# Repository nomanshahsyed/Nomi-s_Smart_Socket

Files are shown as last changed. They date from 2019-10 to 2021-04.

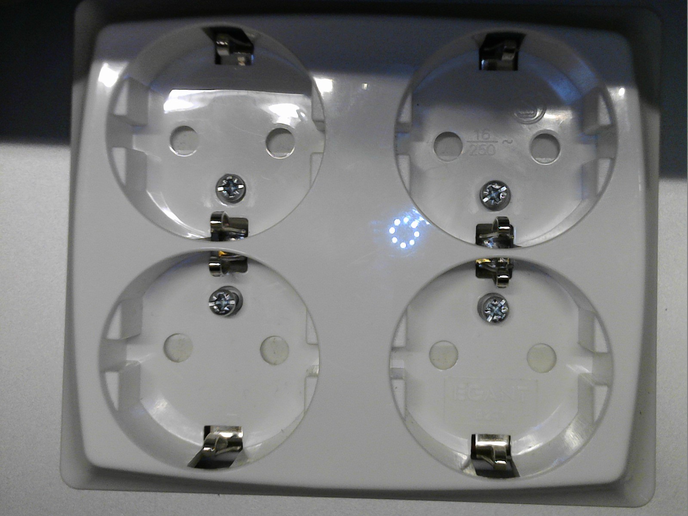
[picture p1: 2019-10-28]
Pictures/WIN_20191028_12_22_07_Pro.jpg

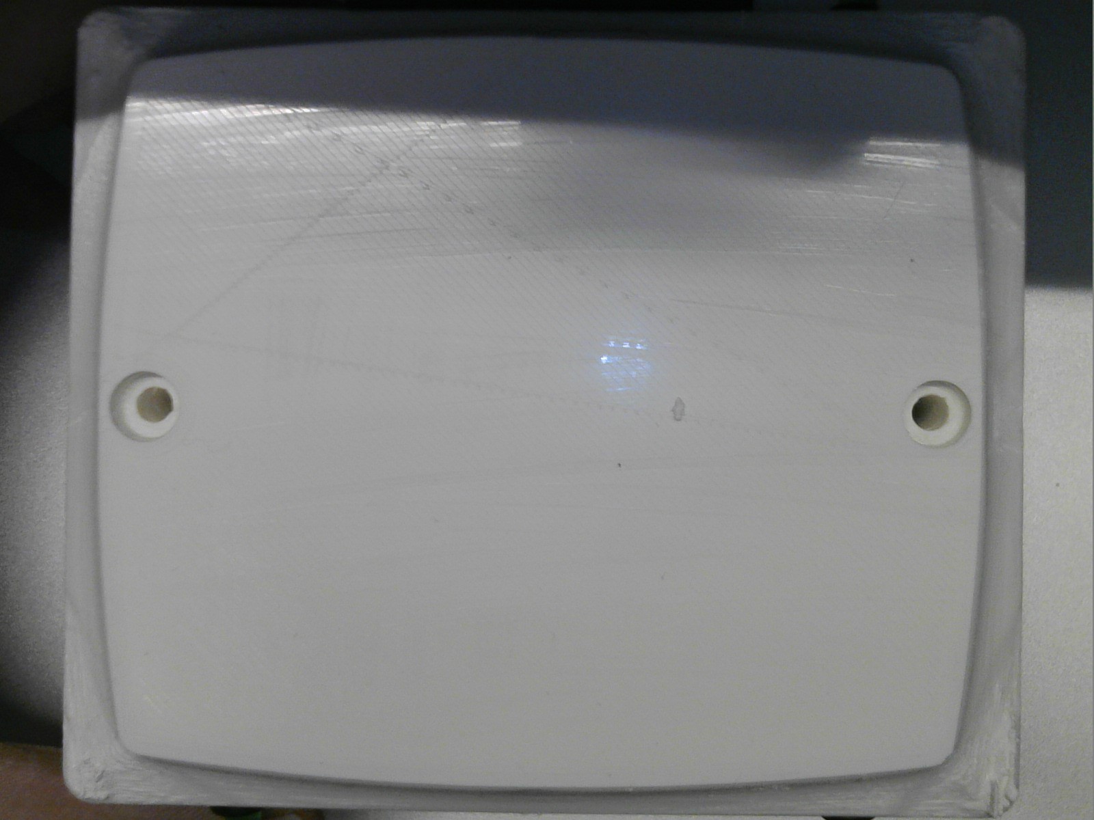
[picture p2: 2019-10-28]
Pictures/WIN_20191028_12_22_18_Pro.jpg

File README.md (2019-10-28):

# Nomi-s_Smart_Socket
WiFi Controlled Smart Socket.

The socket was bought from clas ohlson. The socket is 2x2 Euro socket. The PCB has four relay's along with 4 LED's. The PCB fits inside the socket housing and there is a 3d printed casing for the socket. Step file can be found in the files. 3d Casing was designed by Harri Kuittinen. https://www.linkedin.com/in/harri-kuittinen-link/

Eagle schematics and Layout is attached along with the arduino code. WiFi uC is ESP8266. This version 1 is controlled with Thinger.io which is a cloud platform. You can have 2 devices for free int he platform so just sign up and make a device and copy the device information into the program and upload.

I will also make mobile application for this project and upload here.

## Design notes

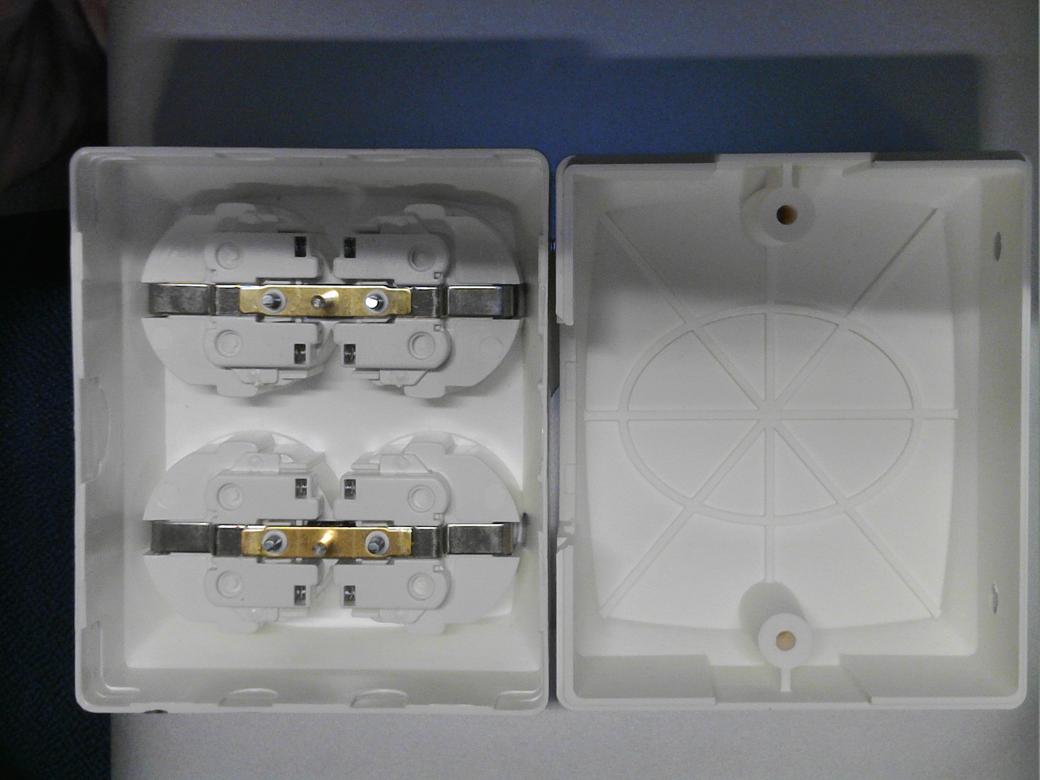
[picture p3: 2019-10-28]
Pictures/WIN_20191028_11_45_18_Pro.jpg

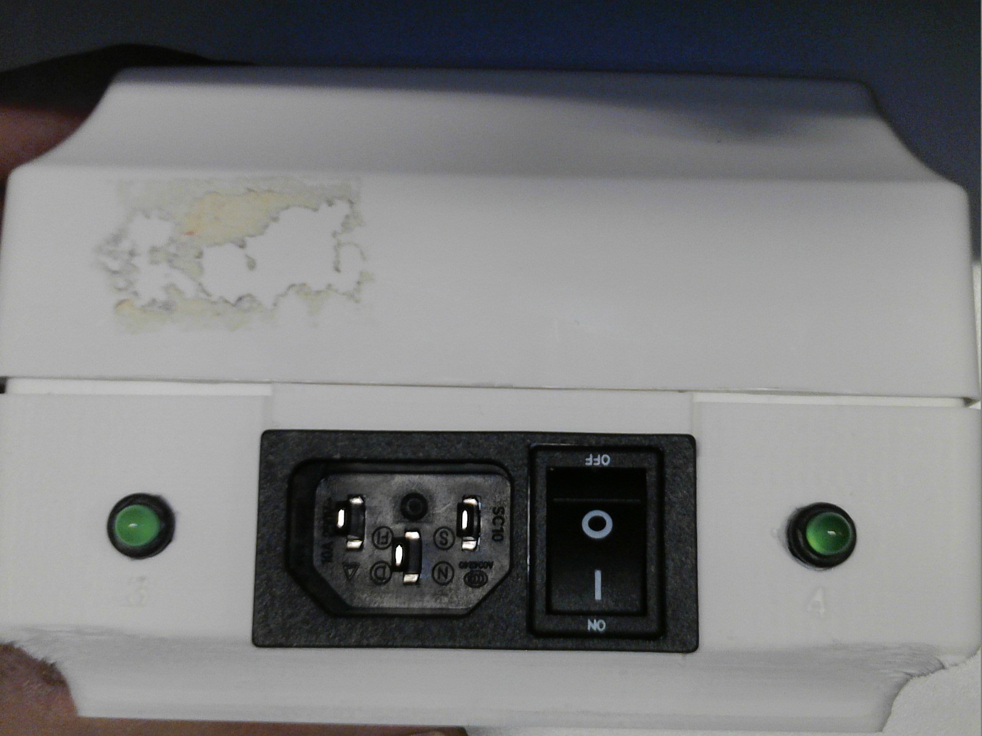
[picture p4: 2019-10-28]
Pictures/WIN_20191028_12_30_31_Pro.jpg

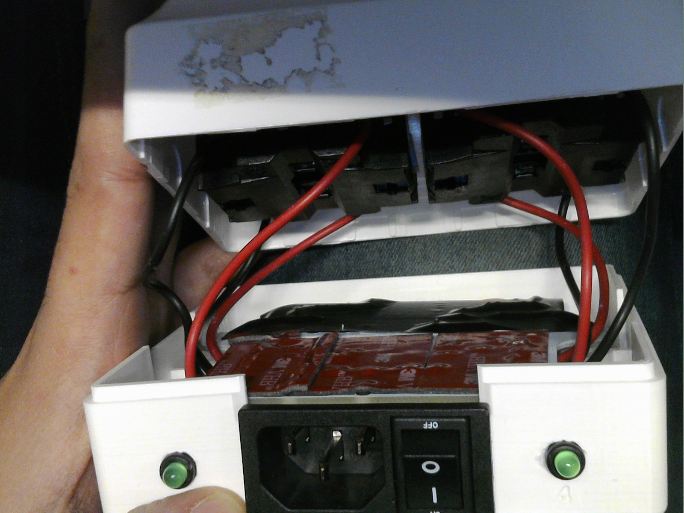
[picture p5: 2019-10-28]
Pictures/WIN_20191028_11_58_56_Pro.jpg

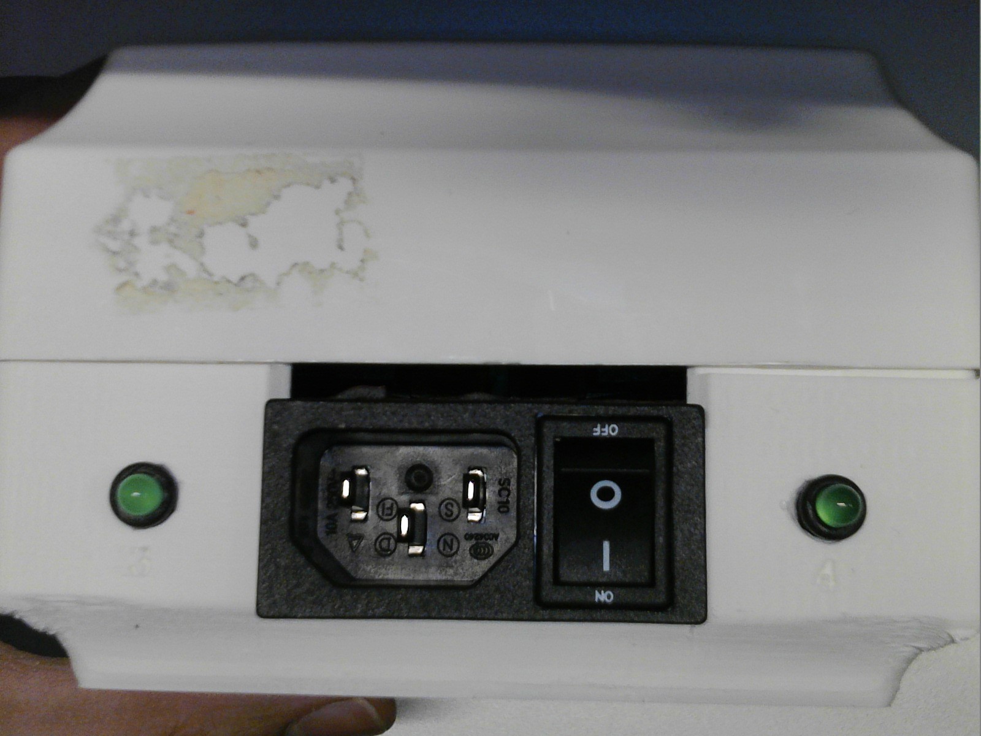
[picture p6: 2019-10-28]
Pictures/WIN_20191028_12_22_13_Pro.jpg

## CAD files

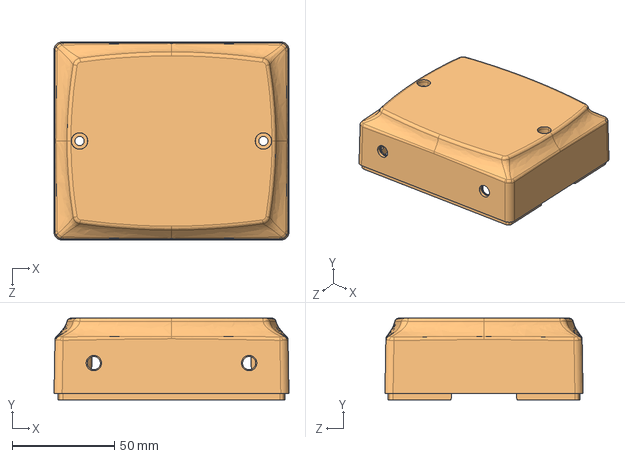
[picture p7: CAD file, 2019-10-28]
Casing_done_by_Harri.STEP
115.0 x 40.0 x 97.0 mm

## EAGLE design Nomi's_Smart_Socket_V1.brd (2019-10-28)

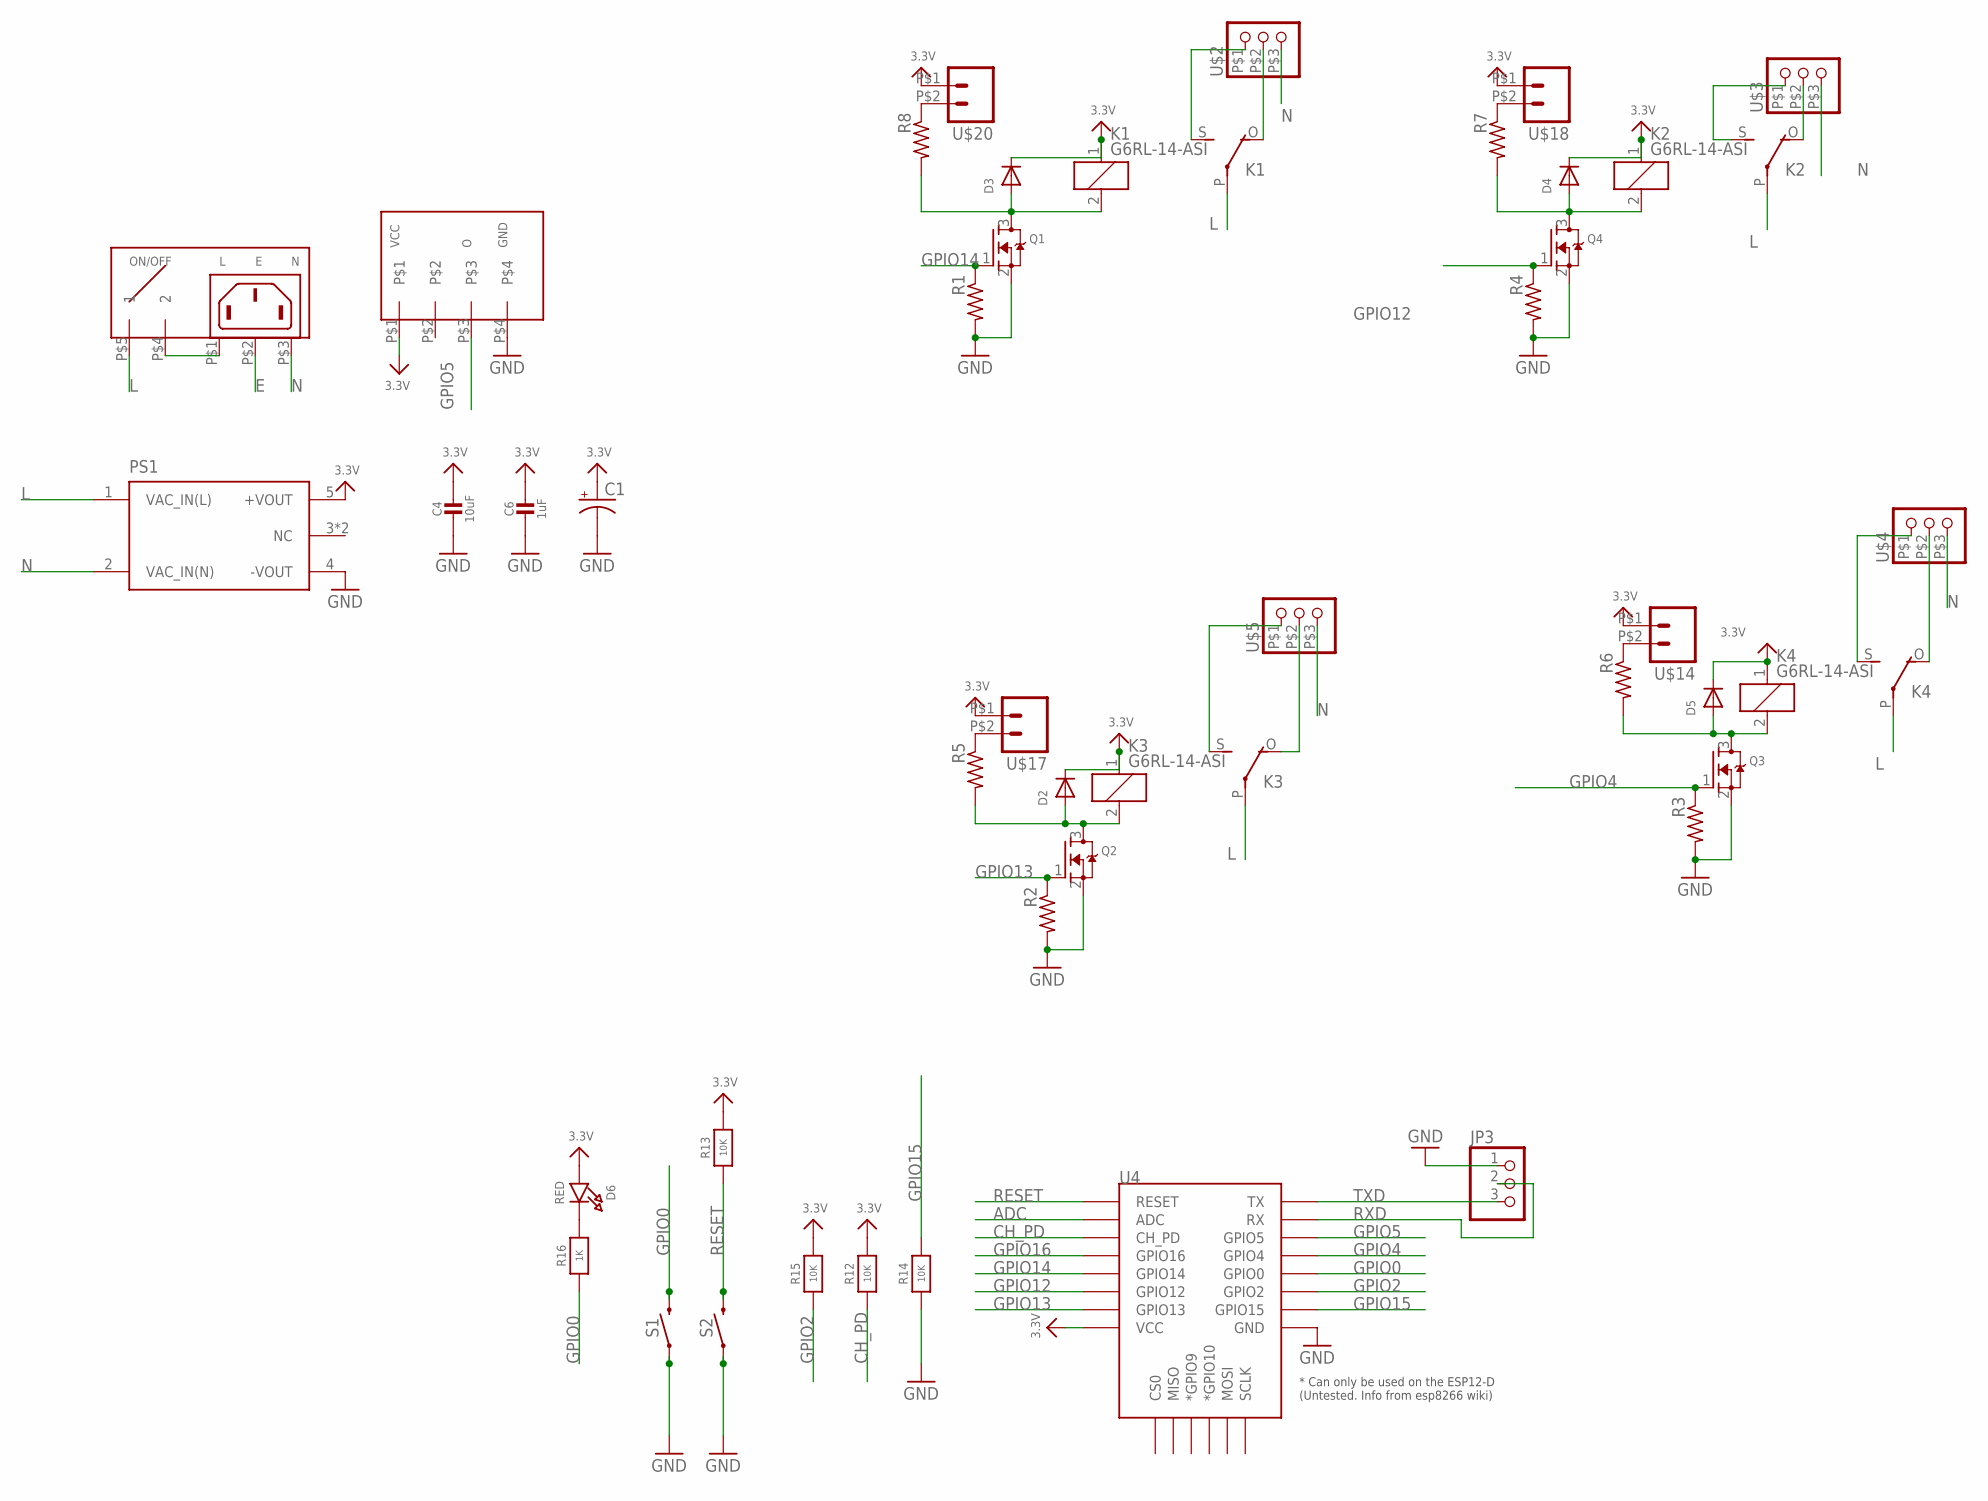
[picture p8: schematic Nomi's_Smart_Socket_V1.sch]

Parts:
C1: CPOL-USE5-10.5; E5-10,5
C4: 10uF; _0805
C6: 1uF; _0603
D2, D3, D4, D5: DIODE_SOD-123FL; SOD-123FL
D6: RED; CHIPLED_0805_NOOUTLINE
JP3: PINHD-1X3; 1X03
K1, K2, K3, K4: G6RL-14-ASI; G6RW
PS1: RAC04-3.3SGBRAC04-3.3SGB-3D; DIP1778W80P508L3670H1500Q6B
Q1, Q2, Q3, Q4: MOSFET-NREFLOW; SOT23
R1, R2, R3, R4: 10k; R0603
R5, R6, R7, R8: 22; R0603
R12, R13, R14, R15: 10K; _0603
R16: 1K; _0603
S1, S2: MOMENTARY-SWITCH-SPST-SMD-4.6X2.8MM; TACTILE_SWITCH_SMD_4.6X2.8MM
U4: ESP12FSMD; ESP12F
U$1: AC-CONN-WITH-SWITCH
U$2, U$3, U$4, U$5: TERM-BLOCK-3POS-5MM5MM; TERM-BLOCK-3POS-5MM
U$13: DHT22
U$14, U$17, U$18, U$20: TERMINAL-BLOCK-2POS-2.54MM

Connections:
3.3V: C1.+, C4.1, C6.1, D2.C, D3.C, D4.C, D5.C, D6.A, K1.1, K2.1, K3.1, K4.1, PS1.5 (+VOUT), R12.2, R13.2, R15.2, U4.3.3V (VCC), U$13.P$1, U$14.P$1 (1), U$17.P$1 (1), U$18.P$1 (1), U$20.P$1 (1)
ADC: U4.ADC
CH_PD: R12.1, U4.EN (CH_PD)
E: U$1.P$2 (EARTH)
GND: C1.-, C4.2, C6.2, JP3.1, PS1.4 (-VOUT), Q1.2 (S), Q2.2 (S), Q3.2 (S), Q4.2 (S), R1.2, R2.2, R3.2, R4.2, R14.1, S1.1, S1.2 (1), S2.1, S2.2 (1), U4.GND, U$13.P$4
GPIO0: R16.1, S1.3 (2), S1.4 (2), U4.GPIO0
GPIO2: R15.1, U4.GPIO2
GPIO4: Q3.1 (G), R3.1, U4.GPIO4
GPIO5: U4.GPIO5, U$13.P$3
GPIO12: Q4.1 (G), R4.1, U4.GPIO12
GPIO13: Q2.1 (G), R2.1, U4.GPIO13
GPIO14: Q1.1 (G), R1.1, U4.GPIO14
GPIO15: R14.2, U4.GPIO15
GPIO16: U4.GPIO16
L: K1.P, K2.P, K3.P, K4.P, PS1.1 (VAC_IN(L)), U$1.P$5 (1)
N: PS1.2 (VAC_IN(N)), U$1.P$3 (N), U$2.P$3 (3), U$3.P$3 (3), U$4.P$3 (3), U$5.P$3 (3)
unnamed: U$1.P$1 (L), U$1.P$4 (2)
unnamed: D5.A, K4.2, Q3.3 (D), R6.2
unnamed: D2.A, K3.2, Q2.3 (D), R5.2
unnamed: D3.A, K1.2, Q1.3 (D), R8.2
unnamed: D6.C, R16.2
unnamed: D4.A, K2.2, Q4.3 (D), R7.2
unnamed: K4.O, U$4.P$2 (2)
unnamed: K2.O, U$3.P$2 (2)
unnamed: R5.1, U$17.P$2 (2)
unnamed: R6.1, U$14.P$2 (2)
unnamed: R7.1, U$18.P$2 (2)
unnamed: R8.1, U$20.P$2 (2)
unnamed: K4.S, U$4.P$1 (1)
unnamed: K3.O, U$5.P$2 (2)
unnamed: K1.S, U$2.P$1 (1)
unnamed: K1.O, U$2.P$2 (2)
unnamed: K2.S, U$3.P$1 (1)
unnamed: K3.S, U$5.P$1 (1)
RESET: R13.1, S2.3 (2), S2.4 (2), U4.RST (RESET)
RXD: JP3.2, U4.RXD (RX)
TXD: JP3.3, U4.TXD (TX)

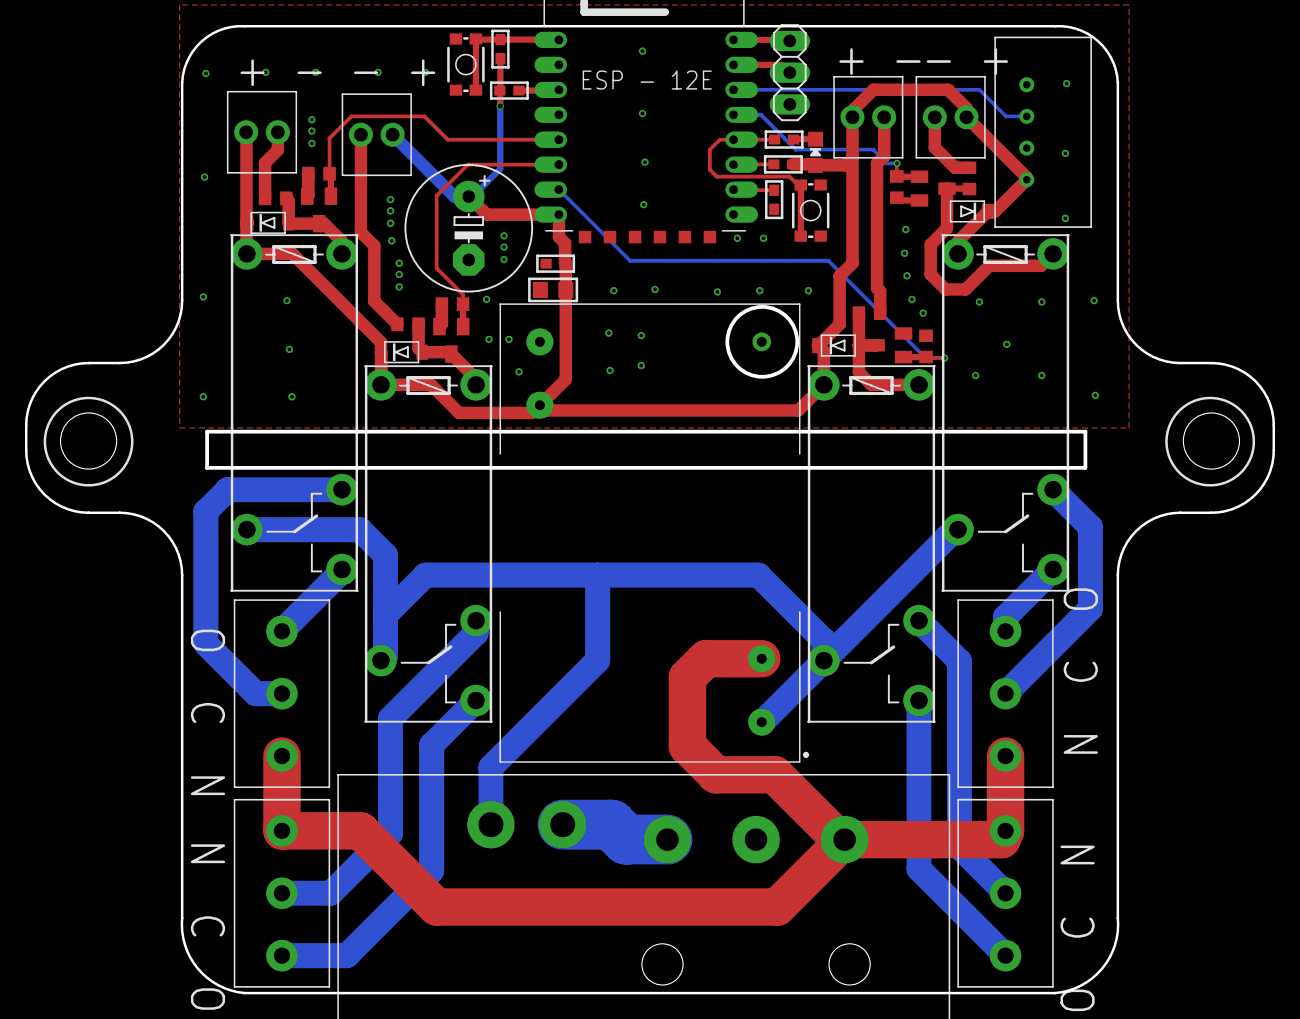
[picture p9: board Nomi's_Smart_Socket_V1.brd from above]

Board: 2 copper layers, 100.0 x 77.5 mm, 44 parts (0 on the bottom side), 34 nets.

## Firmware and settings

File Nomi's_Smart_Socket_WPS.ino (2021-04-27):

#include <ESP8266WiFi.h>
#include <ThingerESP8266.h>

#define USERNAME "USERNAME"
#define DEVICE_ID "DEVICE_ID"
#define DEVICE_CREDENTIAL "DEVICE_CREDENTIAL"

const int relay1 = 14;
const int relay2 = 4;
const int relay3 = 13;
const int relay4 = 12;

ThingerESP8266 thing(USERNAME, DEVICE_ID, DEVICE_CREDENTIAL);

void setup(void)
{
    Serial.begin(115200);

    pinMode(relay1, OUTPUT);
    pinMode(relay2, OUTPUT);
    pinMode(relay3, OUTPUT);
    pinMode(relay4, OUTPUT);

    WiFi.mode(WIFI_STA);
    WiFi.begin("", ""); //If the wifi credentials are stored, esp will try to connect

    digitalWrite(relay1, HIGH); // Just an indication that wps is starting

    delay(5000);

    if (WiFi.status() != WL_CONNECTED)
    {

        Serial.println("\nAttempting connection ...");

        WiFi.beginWPSConfig();

        delay(5000);

        if (WiFi.status() == WL_CONNECTED)
        {
            Serial.println("Connected!");
            Serial.println(WiFi.localIP());
            Serial.println(WiFi.SSID());
            Serial.println(WiFi.macAddress());

            digitalWrite(relay2, HIGH);
            delay(500);
        }
        else
        {
            Serial.println("Connection failed!");
            digitalWrite(relay3, HIGH);
            delay(500);
        }
    }
    else
    {
        Serial.println("\nConnection already established.");
        digitalWrite(relay4, HIGH);
        delay(500);
    }

    digitalWrite(relay1, LOW);
    digitalWrite(relay2, LOW);
    digitalWrite(relay3, LOW);
    digitalWrite(relay4, LOW);

    thing.add_wifi(WiFi.SSID().c_str(), WiFi.psk().c_str());

    thing["relay1"] << digitalPin(relay1);
    thing["relay2"] << digitalPin(relay2);
    thing["relay3"] << digitalPin(relay3);
    thing["relay4"] << digitalPin(relay4);
}

void loop()
{
    thing.handle();
}

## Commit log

2019-10-28 Version 1
    WiFi Controlled Smart Socket.
    The socket was bought from clas ohlson. The socket is 2x2 Euro socket. The PCB has four relay's along with 4 LED's. The PCB fits inside the socket housing and there is a 3d printed casing for the soc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
    Eagle schematics and Layout is attached along with the arduino code. WiFi uC is ESP8266. This version 1 is controlled with Thinger.io which is a cloud platform. You can have 2 devices for free int he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
    [Nomi's_Smart_Socket_V1.brd, Nomi's_Smart_Socket_V1.sch]
2019-10-28 Pictures for assembly.
2021-04-27 Smart Socket with WPS connection with the router.
    Press the WPS button on router when the LED1 turns on.

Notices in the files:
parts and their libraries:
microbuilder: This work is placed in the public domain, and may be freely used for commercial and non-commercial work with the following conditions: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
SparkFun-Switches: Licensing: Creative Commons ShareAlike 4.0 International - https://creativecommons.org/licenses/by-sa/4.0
